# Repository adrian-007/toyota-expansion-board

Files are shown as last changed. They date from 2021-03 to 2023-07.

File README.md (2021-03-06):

# Toyota Expansion Board

This is a firmware source code for [Expansion Board](https://adrian-007.eu/2021/02/21/toyota-expansion-board-intro/) I made for my Toyota Corolla after replacing stock radio unit.

Firmware was written in C++14 for ATmega88 MCU and features:

* DS18B20 temperature reading
* SSD1306 OLED display driver
* Six buttons reading via ADC
* Communication with Pioneer radio unit via digital potentiometer MCP42100
* UART output (logging)

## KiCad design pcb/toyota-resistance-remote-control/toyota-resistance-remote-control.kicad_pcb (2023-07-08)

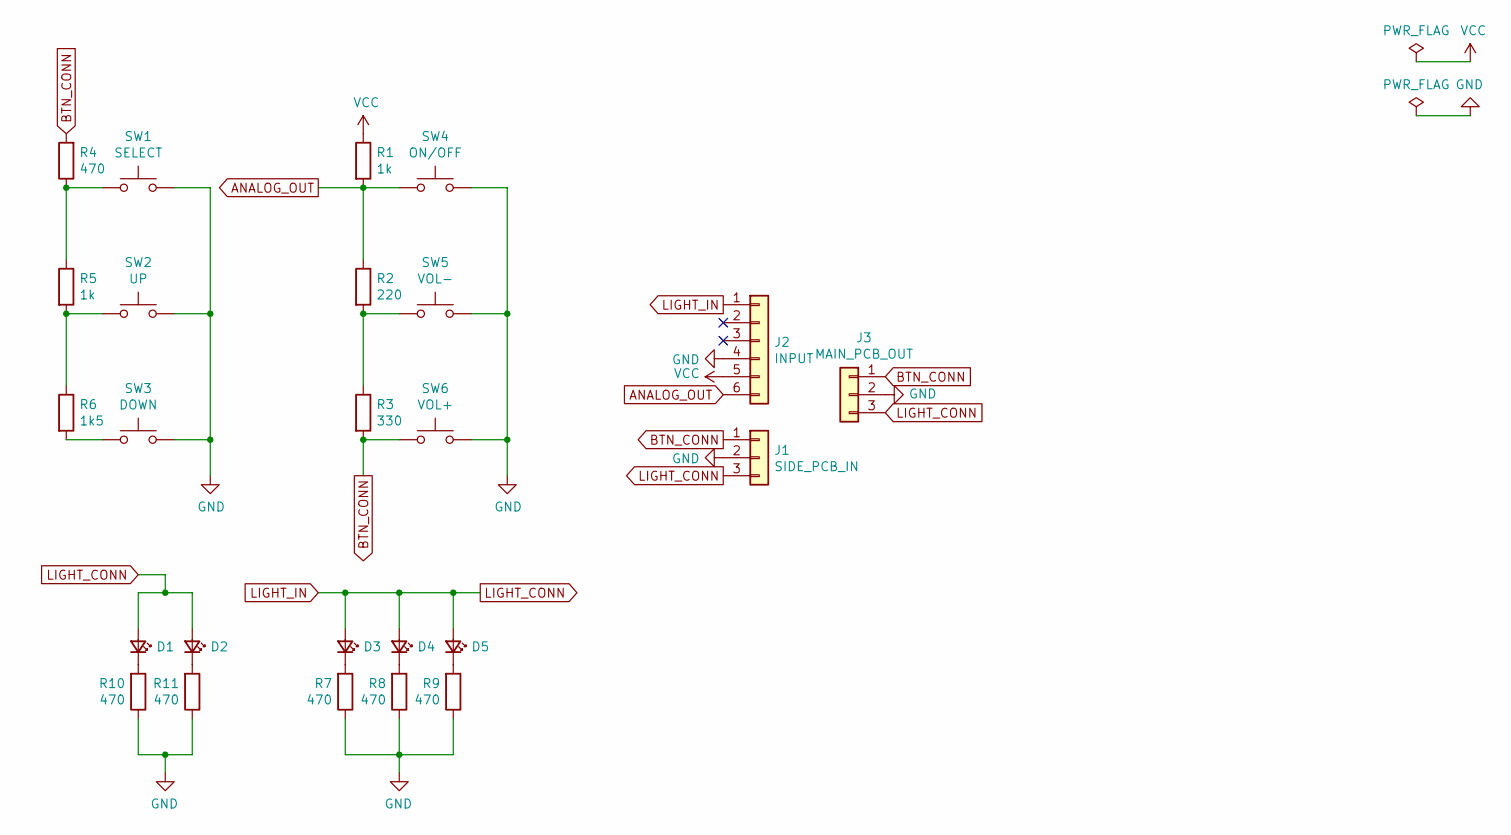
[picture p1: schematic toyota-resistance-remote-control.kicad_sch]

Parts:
D1, D2, D3, D4, D5: LED_Small; LED_D3.0mm
J1: SIDE_PCB_IN; PinHeader_1x03_P2.54mm_Vertical
J2: INPUT; PinHeader_1x06_P2.54mm_Vertical
J3: MAIN_PCB_OUT; PinHeader_1x03_P2.54mm_Vertical
R1, R5: 1k; R_1206_3216Metric_Pad1.42x1.75mm_HandSolder
R2: 220; R_1206_3216Metric_Pad1.42x1.75mm_HandSolder
R3: 330; R_1206_3216Metric_Pad1.42x1.75mm_HandSolder
R4, R7, R8, R9, R10, R11: 470; R_1206_3216Metric_Pad1.42x1.75mm_HandSolder
R6: 1k5; R_1206_3216Metric_Pad1.42x1.75mm_HandSolder
SW1: SELECT; SW_PUSH_6mm
SW2: UP; SW_PUSH_6mm
SW3: DOWN; SW_PUSH_6mm
SW4: ON/OFF; SW_PUSH_6mm
SW5: VOL-; SW_PUSH_6mm
SW6: VOL+; SW_PUSH_6mm

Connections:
ANALOG_OUT: J2.6, R1.2, R2.1, SW4.1
BTN_CONN: J1.1, J3.1, R3.2, R4.2, SW6.1
GND: J1.2, J2.4, J3.2, R7.1, R8.1, R9.1, R10.1, R11.1, SW1.2, SW2.2, SW3.2, SW4.2, SW5.2, SW6.2
LIGHT_CONN: D1.2 (A), D2.2 (A), D3.2 (A), D4.2 (A), D5.2 (A), J1.3, J2.1, J3.3
unnamed: D1.1 (K), R10.2
unnamed: D2.1 (K), R11.2
unnamed: D3.1 (K), R7.2
unnamed: D4.1 (K), R8.2
unnamed: D5.1 (K), R9.2
unnamed: R2.2, R3.1, SW5.1
unnamed: R4.1, R5.1, SW1.1
unnamed: R5.2, R6.1, SW2.1
unnamed: R6.2, SW3.1
VCC: J2.5, R1.1

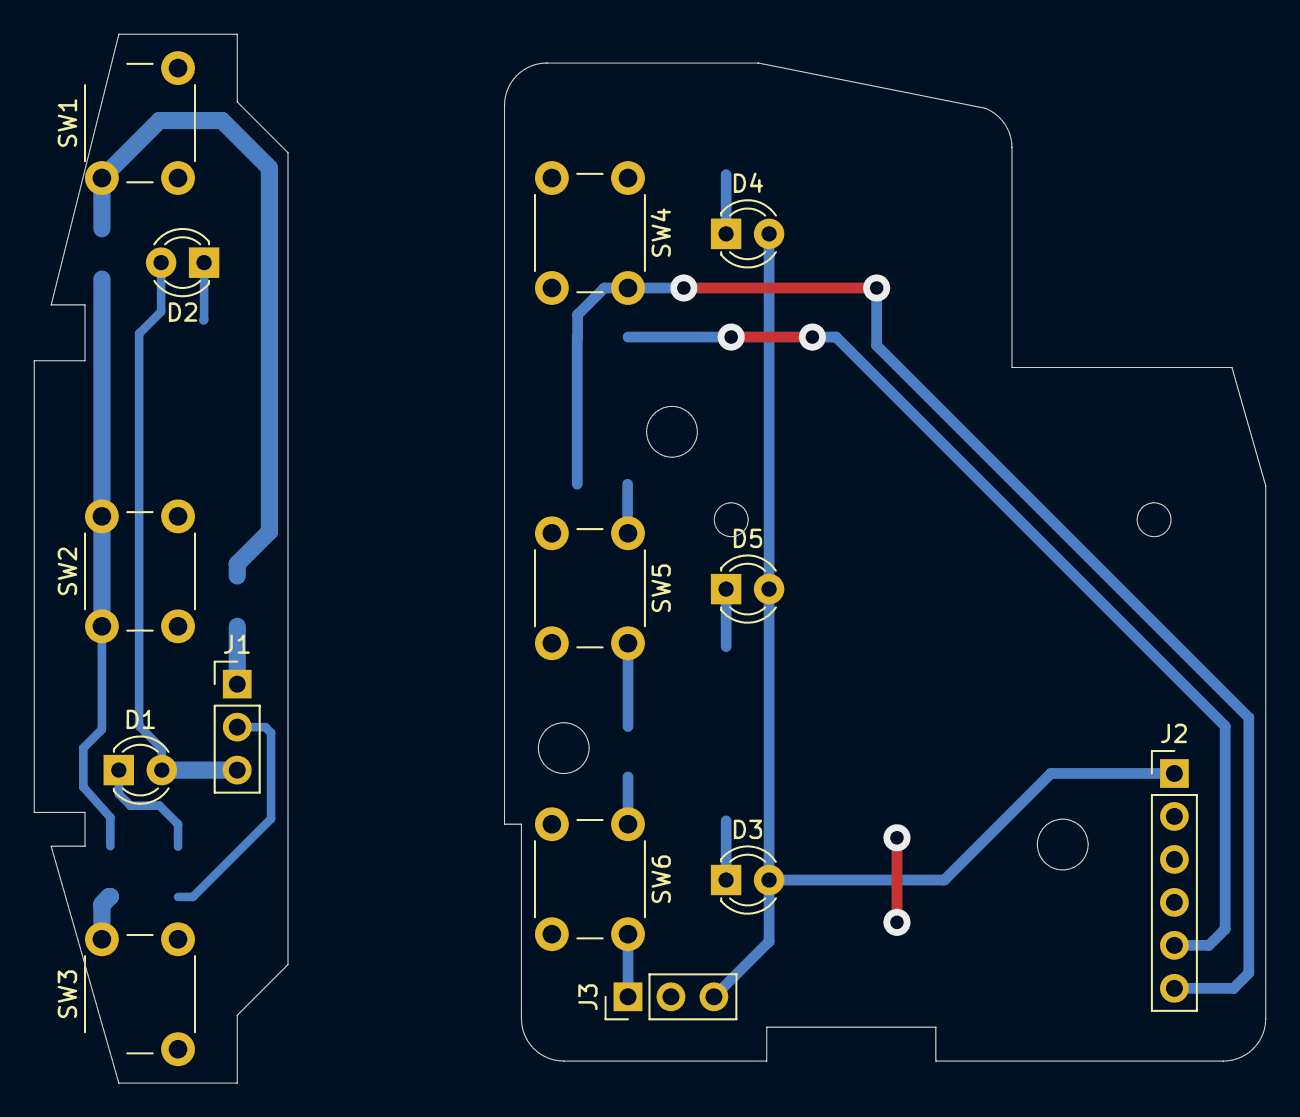
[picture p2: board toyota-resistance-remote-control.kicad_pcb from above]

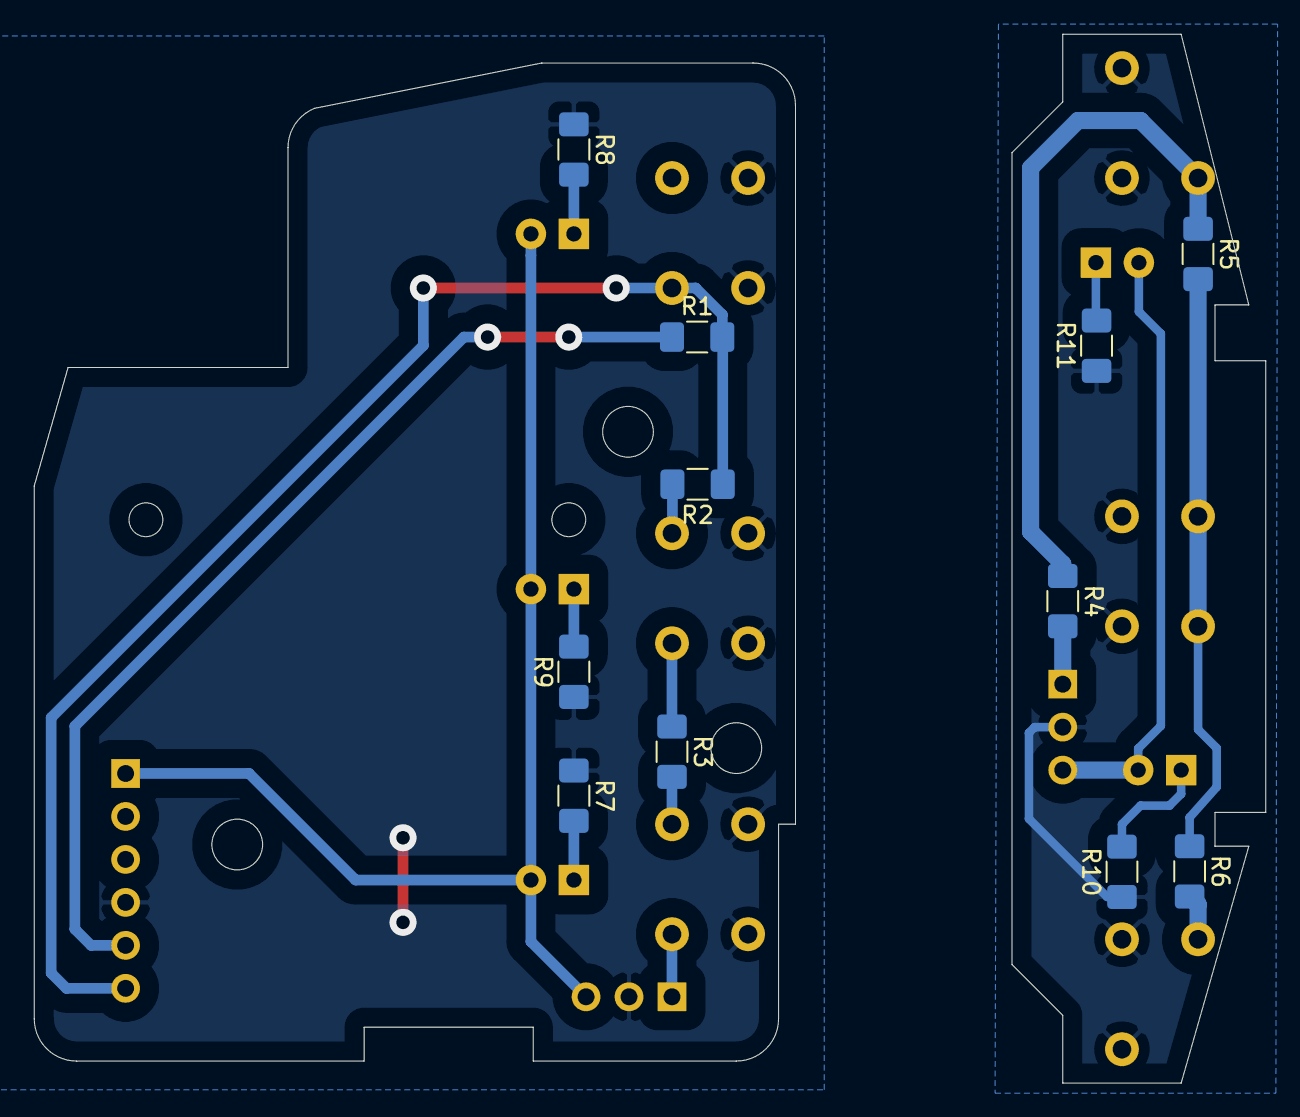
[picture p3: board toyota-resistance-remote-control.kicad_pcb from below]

Board: 2 copper layers, 72.8 x 62.0 mm, 25 parts (11 on the bottom side), 14 nets.

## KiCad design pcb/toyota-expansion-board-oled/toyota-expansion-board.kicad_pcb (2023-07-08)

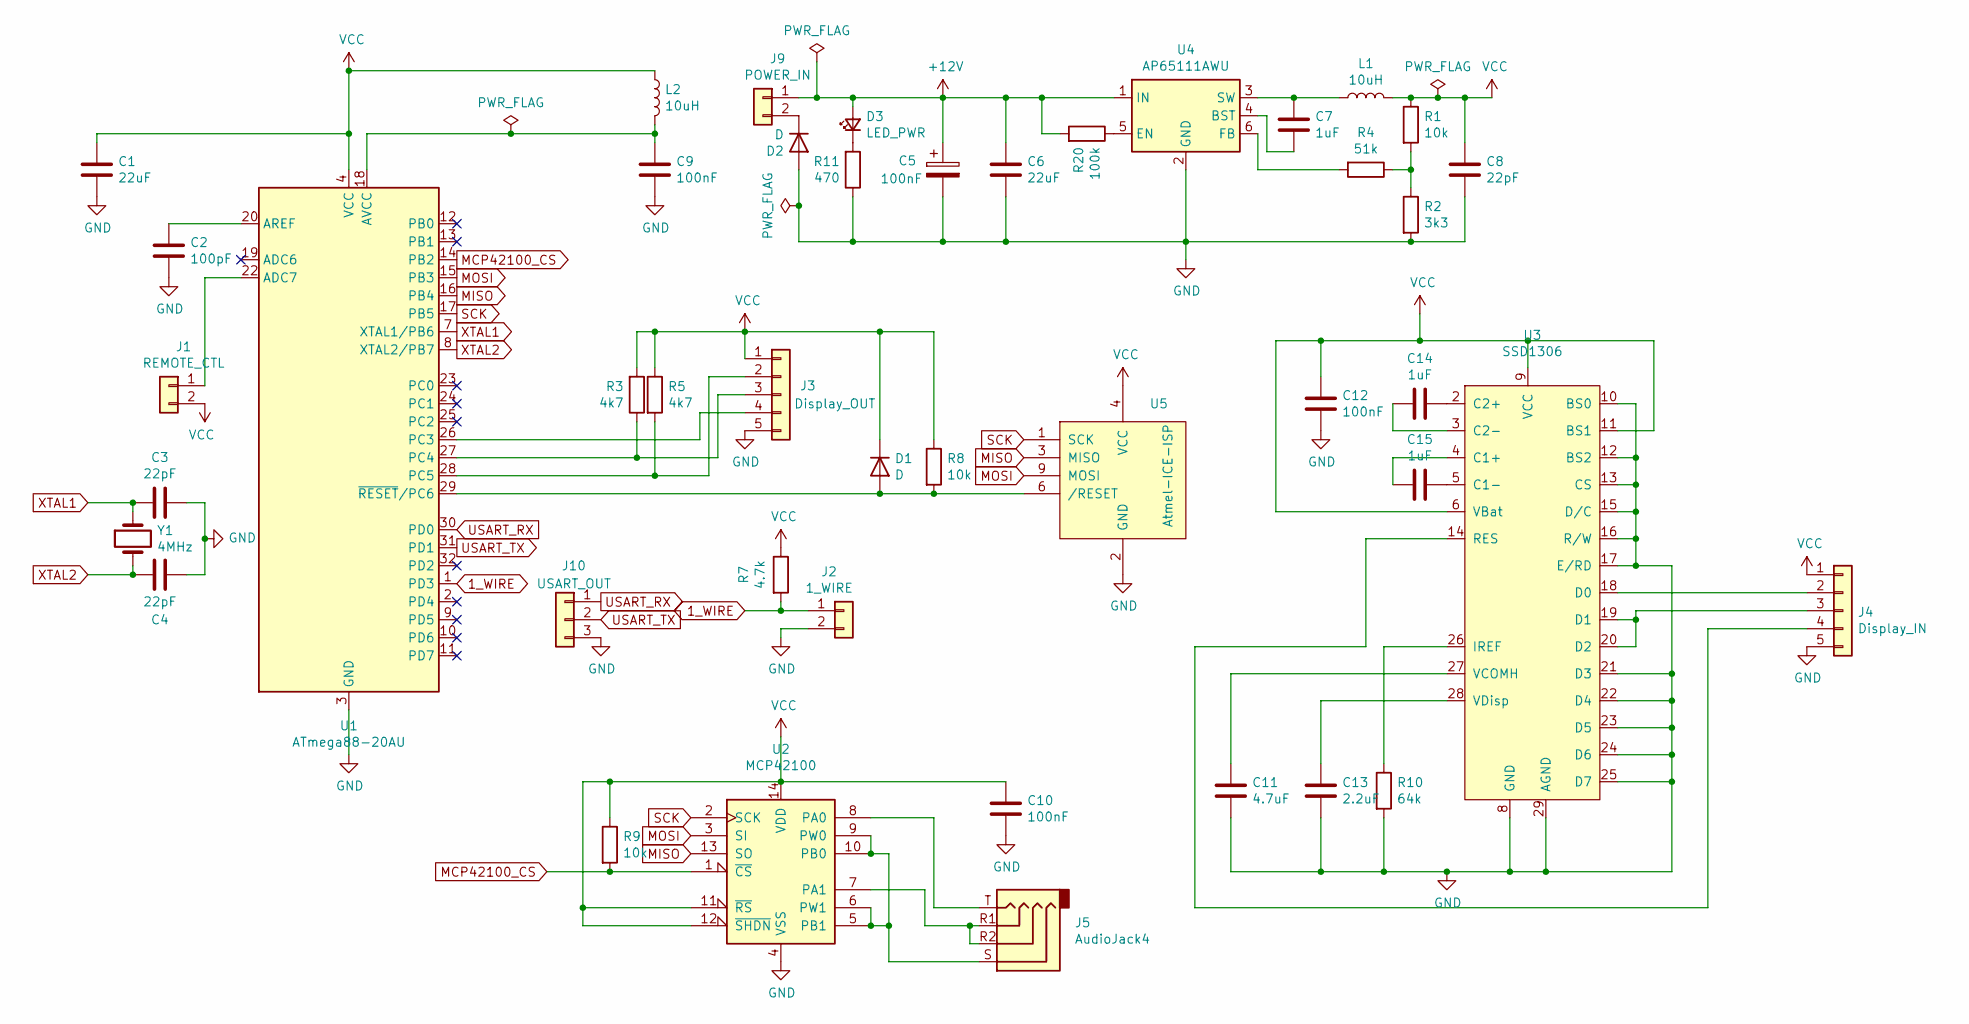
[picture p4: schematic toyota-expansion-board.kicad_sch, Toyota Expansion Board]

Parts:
C1, C6: 22uF; CP_Elec_6.3x5.4
C2: 100pF; C_1206_3216Metric_Pad1.33x1.80mm_HandSolder
C3, C4, C8: 22pF; C_1206_3216Metric_Pad1.33x1.80mm_HandSolder
C5, C9, C10, C12: 100nF; C_1206_3216Metric_Pad1.33x1.80mm_HandSolder
C7, C14, C15: 1uF; CP_Elec_4x5.4
C11: 4.7uF; CP_Elec_6.3x5.4
C13: 2.2uF; CP_Elec_6.3x5.4
D1, D2: D; D_DO-15_P5.08mm_Vertical_AnodeUp
D3: LED_PWR; LED_D3.0mm
J1: REMOTE_CTL; TerminalBlock_bornier-2_P5.08mm
J2: 1_WIRE; TerminalBlock_bornier-2_P5.08mm
J3: Display_OUT; PinHeader_1x05_P2.54mm_Vertical
J4: Display_IN; PinHeader_1x05_P2.54mm_Vertical
J5: AudioJack4; PJ218-SMT-LW
J9: POWER_IN; TerminalBlock_bornier-2_P5.08mm
J10: USART_OUT; PinHeader_1x03_P2.54mm_Vertical
L1, L2: 10uH; DLG-0705_HandSolder
R1, R8, R9: 10k; R_1206_3216Metric_Pad1.30x1.75mm_HandSolder
R2: 3k3; R_1206_3216Metric_Pad1.30x1.75mm_HandSolder
R3, R5: 4k7; R_1206_3216Metric_Pad1.30x1.75mm_HandSolder
R4: 51k; R_1206_3216Metric_Pad1.30x1.75mm_HandSolder
R7: 4.7k; R_1206_3216Metric_Pad1.30x1.75mm_HandSolder
R10: 64k; R_1206_3216Metric_Pad1.30x1.75mm_HandSolder
R11: 470; R_1206_3216Metric_Pad1.30x1.75mm_HandSolder
R20: 100k; R_1206_3216Metric_Pad1.30x1.75mm_HandSolder
U1: ATmega88-20AU; TQFP-32_7x7mm_P0.8mm
U2: MCP42100; SOIC-14_3.9x8.7mm_P1.27mm
U3: SSD1306; OLED-AG-L-12864
U4: AP65111AWU; TSOT-23-6
U5: Atmel-ICE-ISP; Atmel-ICE_IDC_2x05_P1.27mm_Vertical
Y1: 4MHz; Crystal_HC18-U_Vertical

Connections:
1_WIRE: J2.1, R7.2, U1.1 (PD3)
+12V: C5.1, C6.1, D3.2 (A), J9.1, R20.2, U4.1 (IN)
GND: C1.2, C2.2, C3.1, C4.2, C5.2, C6.2, C8.2, C9.2, C10.2, C11.2, C12.2, C13.2, D2.2 (A), J2.2, J3.5, J4.5, J10.3, R2.2, R10.2, R11.1, U1.3 (GND), U1.5 (GND), U1.21 (GND), U2.4 (VSS), U3.8 (GND), U3.10 (BS0), U3.12 (BS2), U3.13 (CS), U3.15 (D/C), U3.16 (R/W), U3.17 (E/RD), U3.21 (D3), U3.22 (D4), U3.23 (D5), U3.24 (D6), U3.25 (D7), U3.29 (AGND), U4.2 (GND), U5.2 (GND)
MCP42100_CS: R9.2, U1.14 (PB2), U2.1 (~CS)
MISO: U1.16 (PB4), U2.13 (SO), U5.3 (MISO)
MOSI: U1.15 (PB3), U2.3 (SI), U5.9 (MOSI)
unnamed: C2.1, U1.20 (AREF)
unnamed: C7.1, L1.1, U4.3 (SW)
unnamed: C7.2, U4.4 (BST)
unnamed: C9.1, L2.2, U1.18 (AVCC)
unnamed: C11.1, U3.27 (VCOMH)
unnamed: C13.1, U3.28 (VDisp)
unnamed: C14.1, U3.3 (C2-)
unnamed: C14.2, U3.2 (C2+)
unnamed: C15.1, U3.5 (C1-)
unnamed: C15.2, U3.4 (C1+)
unnamed: D1.2 (A), R8.2, U1.29 (~RESET/PC6), U5.6 (/RESET)
unnamed: D2.1 (K), J9.2
unnamed: D3.1 (K), R11.2
unnamed: J1.1, U1.22 (ADC7)
unnamed: J3.2, R5.2, U1.28 (PC5)
unnamed: J3.3, R3.1, U1.27 (PC4)
unnamed: J3.4, U1.26 (PC3)
unnamed: J4.2, U3.18 (D0)
unnamed: J4.3, U3.19 (D1), U3.20 (D2)
unnamed: J4.4, U3.14 (RES)
unnamed: J5.R1, J5.R2, U2.7 (PA1)
unnamed: J5.S, U2.5 (PB1), U2.6 (PW1), U2.9 (PW0), U2.10 (PB0)
unnamed: J5.T, U2.8 (PA0)
unnamed: R1.2, R2.1, R4.1
unnamed: R4.2, U4.6 (FB)
unnamed: R10.1, U3.26 (IREF)
unnamed: R20.1, U4.5 (EN)
SCK: U1.17 (PB5), U2.2 (SCK), U5.1 (SCK)
USART_RX: J10.1, U1.30 (PD0)
USART_TX: J10.2, U1.31 (PD1)
VCC: C1.1, C8.1, C10.1, C12.1, D1.1 (K), J1.2, J3.1, J4.1, L1.2, L2.1, R1.1, R3.2, R5.1, R7.1, R8.1, R9.1, U1.4 (VCC), U1.6 (VCC), U2.11 (~RS), U2.12 (~SHDN), U2.14 (VDD), U3.6 (VBat), U3.9 (VCC), U3.11 (BS1), U5.4 (VCC)
XTAL1: C3.2, U1.7 (XTAL1/PB6), Y1.1
XTAL2: C4.1, U1.8 (XTAL2/PB7), Y1.2

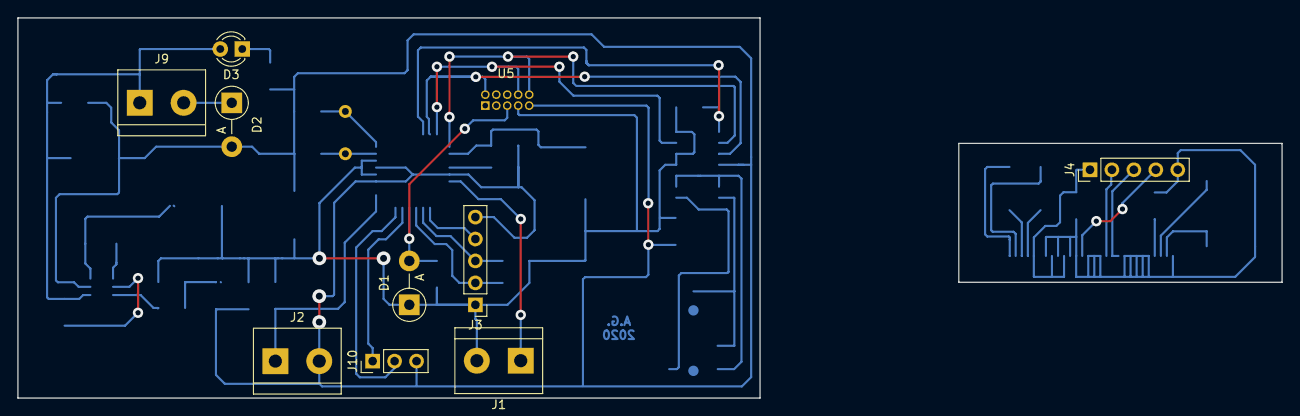
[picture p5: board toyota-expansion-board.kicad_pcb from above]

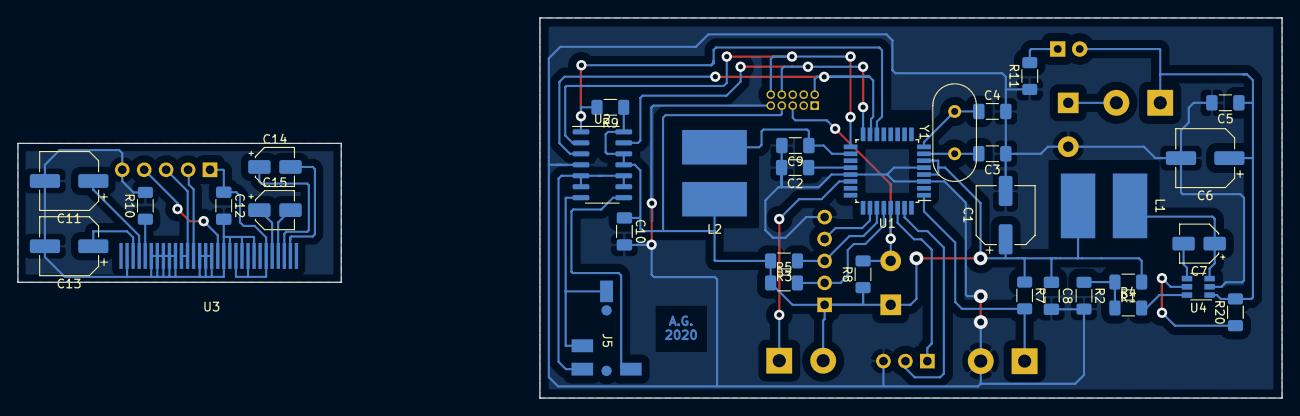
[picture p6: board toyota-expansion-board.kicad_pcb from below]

Board: 2 copper layers, 85.9 x 44.0 mm, 44 parts (34 on the bottom side), 39 nets.

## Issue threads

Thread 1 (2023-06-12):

Great work!

georgeboot, 2023-06-12:
Great work!

I would live to convert the buttons on my wheel as well, so I can use them on my new 2DIN radio.

Would you consider open sourcing / sharing the design for the 2 steering wheel pcb's? Would love to print 1 for my own car.

Thanks!

adrian-007, 2023-07-08:
Thanks!

I've committed KiCAD files, you can find them under "pcb" folder.

Closed 2023-07-08.

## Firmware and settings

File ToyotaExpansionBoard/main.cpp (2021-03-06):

/*
 * Copyright (C) 2021 adrian_007, adrian-007 on o2 point pl
 *
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
 * You should have received a copy of the GNU General Public License
 * along with this program; if not, write to the Free Software
 * Foundation, Inc., 59 Temple Place - Suite 330, Boston, MA 02111-1307, USA.
 */

#include "Serial.h"
#include "MCP42100.h"
#include "SSD1306.h"
#include "DS18B20.h"
#include "ADCButtons.h"

#include <util/delay.h>
#include <avr/interrupt.h>
#include <avr/sleep.h>
#include <avr/wdt.h>

ISR(ADC_vect)
{
    ADCButtons::instance().newSample(ADC);
}

ISR(TIMER0_COMPA_vect)
{
    ADCButtons::instance().poll();
}

ISR(TIMER1_COMPA_vect)
{
    DS18B20::poll();
}

void disable_wdt() __attribute__((naked, used, section(".init3")));

void disable_wdt()
{
    MCUSR = 0;
    wdt_disable();
}

void initTimer0()
{
    // CTC mode
    TCCR0A |= (1 << WGM01); 
    // Prescaler = 1024
    TCCR0B |= (1 << CS02) | (0 << CS01) | (1 << CS00);

    OCR0A = 32;
    // Enable COMPA interrupt
    TIMSK0 |= (1 << OCIE0A);
}

void initTimer1()
{
    // CTC mode, prescaler = 256
    TCCR1B |= (1 << WGM12) | (1 << CS12);
    // F_CPU / 256 => interrupt every second
    OCR1A = 15625;
    // Enable COMPA interrupt
    TIMSK1 |= (1 << OCIE1A);    
}

int main(void)
{
    Serial::init();
    
    DEBUG_PRINT("Initializing modules");

    TWI::init();
    SSD1306::init();
    DS18B20::init();
    ADCButtons::instance().init();

    initTimer0();
    initTimer1();

    // Enable Watchdog
    wdt_enable(WDTO_4S);

    // Enable interrupts
    sei();

    Serial::println("Entering main loop.");
    Serial::println();

    int8_t temp { 90 };
    while (true) {
        {
            InterruptGuard ig {};
            wdt_reset();
            temp = DS18B20::lastTemperatureValue();
        }

        SSD1306::drawTemp(temp);

        _delay_ms(200);
    }
}

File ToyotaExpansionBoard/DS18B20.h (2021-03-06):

/*
 * Copyright (C) 2021 adrian_007, adrian-007 on o2 point pl
 *
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
 * You should have received a copy of the GNU General Public License
 * along with this program; if not, write to the Free Software
 * Foundation, Inc., 59 Temple Place - Suite 330, Boston, MA 02111-1307, USA.
 */

#pragma once

#include <avr/io.h>
#include <util/delay.h>

#include "InterruptGuard.h"
#include "Serial.h"

#define DS_PORT       PORTD
#define DS_DDR        DDRD
#define DS_PIN        PIND
#define DS_PIN_NUM    PIND3

class DS18B20
{
public:
    static void init()
    {
        if (!oneWireInit()) {
            DEBUG_PRINT(" Sensor not present");
            return;
        }

        uint8_t sp[9] { 0 };
        bool changeResolution { true };

        if (readScratchPad(sp)) {
            auto resolution { sp[4] >> 5 };
            
            switch (resolution) {
                case 0:
                    DEBUG_PRINT(" Sensor present, resolution: ", 9, "-bits");
                    changeResolution = false;
                    break;
                case 1:
                    DEBUG_PRINT(" Sensor present, resolution: ", 10, "-bits");
                    break;
                case 2:
                    DEBUG_PRINT(" Sensor present, resolution: ", 11, "-bits");
                    break;
                case 3:
                    DEBUG_PRINT(" Sensor present, resolution: ", 12, "-bits");
                    break;
                default:
                    DEBUG_PRINT(" Sensor present, unknown resolution - ", ", read value: ", resolution);
                    break;
            }
            
        }
        else {
            DEBUG_PRINT(" Sensor not present, cannot read scratchpad");
        }

        if (changeResolution) {
            // 9-bit resolution
            writeScratchPad(0xFF, 0xFF, 0x00);
            commitScratchPad();    
        }
    }

    /**
     * Method should be called every second
     */
    static void poll()
    {
        constexpr uint8_t samplesPerMinute { 12 };
        constexpr uint8_t ticksThreshold { 60 / samplesPerMinute };

        static volatile bool converting { false };
        static volatile uint8_t ticks { ticksThreshold };

        if (++ticks < ticksThreshold)
            return;

        if (!converting) {
            converting = startConversion();
            
            if (!converting) {
                lastTemperatureValue() = 90;
            }
        }
        else {
            converting = false;
            ticks = 0;

            lastTemperatureValue() = readTemp();
        }
    }

    static volatile int8_t& lastTemperatureValue()
    {
        static volatile int8_t lastTemp = 90;
        return lastTemp;
    }

private:
    enum Commands : uint8_t
    {
        SkipROM            = 0xCC,
        StartConversion    = 0x44,
        ReadScratchPad     = 0xBE,
        WriteScratchPad    = 0x4E,
        CommitScratchPad   = 0x48
    };

    static int8_t readTemp()
    {
        uint8_t sp[9] { 0 };
        if (!readScratchPad(sp))
            return 127;

        int16_t temp = ((int16_t)(sp[1] << 8) + sp[0]) / 16;
        return (int8_t)(temp);
    }

    static bool startConversion()
    {
        if (!oneWireInit()) {
            DEBUG_PRINT("Could not initialize 1-Wire reset pulse prior to ", "starting conversion");
            return false;
        }

        oneWireWrite(Commands::SkipROM, Commands::StartConversion);
        oneWireStrongPullup();
        return true;
    }

    static bool readScratchPad(uint8_t scratchPad[9])
    {
        if (!oneWireInit()) {
            DEBUG_PRINT("Could not initialize 1-Wire reset pulse prior to ", "reading scratch pad data");
            return false;
        }

        oneWireWrite(Commands::SkipROM, Commands::ReadScratchPad);

        scratchPad[0] = oneWireRead();
        scratchPad[1] = oneWireRead();
        scratchPad[2] = oneWireRead();
        scratchPad[3] = oneWireRead();
        scratchPad[4] = oneWireRead();
        scratchPad[5] = oneWireRead();
        scratchPad[6] = oneWireRead();
        scratchPad[7] = oneWireRead();
        scratchPad[8] = oneWireRead();

        return calculateCRC(&scratchPad[0], 8) == scratchPad[8];
    }

    static bool writeScratchPad(uint8_t th, uint8_t tl, uint8_t config)
    {
        if (!oneWireInit()) {
            DEBUG_PRINT("Could not initialize 1-Wire reset pulse prior to ", "writing scratch pad data");
            return false;
        }

        oneWireWrite(Commands::SkipROM, Commands::WriteScratchPad, th, tl, config);
        return true;
    }

    static bool commitScratchPad()
    {
        if (!oneWireInit()) {
            DEBUG_PRINT("Could not initialize 1-Wire reset pulse prior to ", "commiting scratch pad data to EEPROM");
            return false;
        }

        oneWireWrite(Commands::SkipROM, Commands::CommitScratchPad);
        oneWireStrongPullup();
        _delay_ms(15);
        return true;
    }

    inline static void oneWireStrongPullup()
    {
        pullUp();
        tx();
    }

    static bool oneWireInit()
    {
        InterruptGuard ig {};

        pullUp();
        tx();
        pullDown();

        _delay_us(500); // 480 us + 20 us of margin
        rx();
        _delay_us(80); // 60 us + 20 us of margin
        
        bool presence { false };
        uint16_t remainingSleep { 500 };

        while (remainingSleep > 0) {
            if (!presence && !pin()) {
                presence = true;
            }

            --remainingSleep;
            _delay_us(1);
        }

        pullUp();
        tx();

        return presence;
    }
    
    static void oneWireWrite(auto value)
    {
        static_assert(sizeof(value) == 1, "You may write at most one byte at a time");

        constexpr auto writeBit = [](bool bit) {
            InterruptGuard ig {};

            pullDown();
            bit ? _delay_us(8) : _delay_us(80);

            pullUp();
            bit ? _delay_us(80) : _delay_us(8);
        };

        pullUp();
        tx();

        writeBit(value & (1 << 0));
        writeBit(value & (1 << 1));
        writeBit(value & (1 << 2));
        writeBit(value & (1 << 3));
        writeBit(value & (1 << 4));
        writeBit(value & (1 << 5));
        writeBit(value & (1 << 6));
        writeBit(value & (1 << 7));
    }

    template<typename...A>
    inline static void oneWireWrite(auto value, A...args)
    {
        oneWireWrite(value);
        oneWireWrite(args...);
    }

    static uint8_t oneWireRead()
    {
        constexpr auto readBit = [](auto pos) -> uint8_t {
            InterruptGuard ig {};

            pullUp();
            tx();

            pullDown();
            _delay_us(2);

            rx();
            _delay_us(5);
        
            uint8_t bit = 0;

            for (auto i { 0u }; i < 5; ++i) {
                if (pin())
                    bit = 1;
                _delay_us(1);
            }

            _delay_us(45);
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

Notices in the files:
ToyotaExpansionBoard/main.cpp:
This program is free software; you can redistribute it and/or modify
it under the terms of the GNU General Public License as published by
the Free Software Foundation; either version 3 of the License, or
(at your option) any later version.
